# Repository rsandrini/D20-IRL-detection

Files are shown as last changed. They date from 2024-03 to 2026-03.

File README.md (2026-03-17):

# Real-time D20 Dice Detection with Raspberry Pi

Physical D20 dice roller with real-time face detection. A servo motor rolls the dice, a USB camera captures the result, and a YOLOv8n TFLite model running on a Raspberry Pi classifies which face is showing (1–20). Results are exposed via a Flask REST API and web UI.

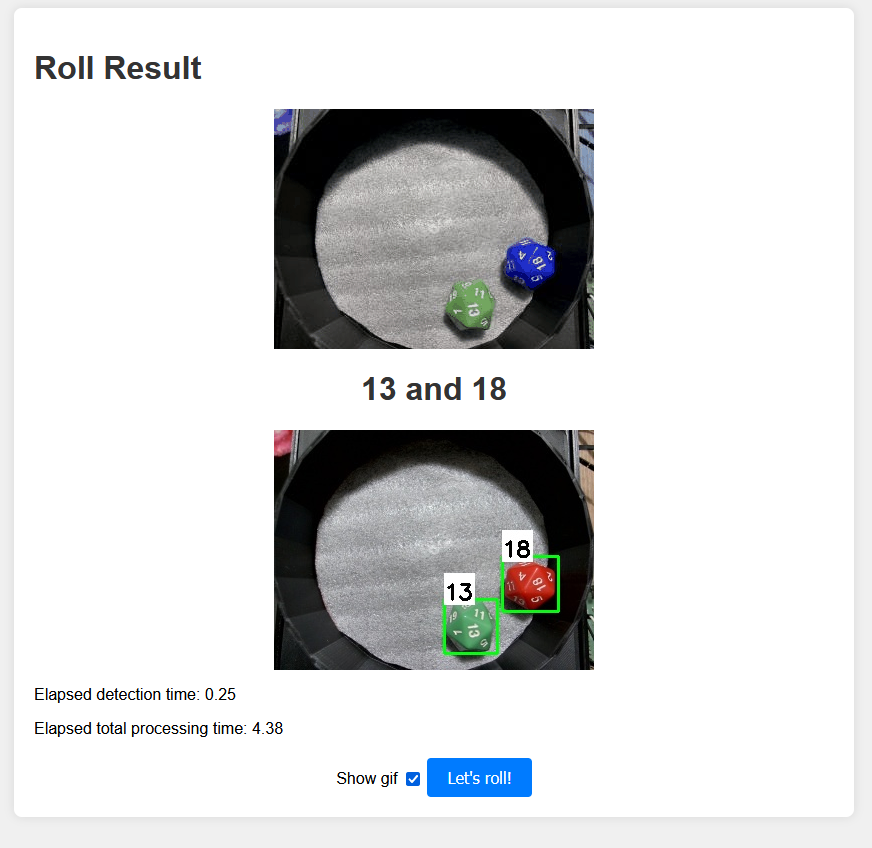
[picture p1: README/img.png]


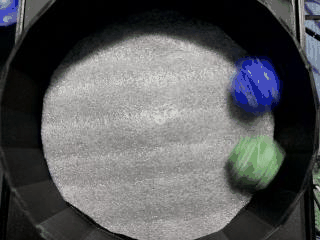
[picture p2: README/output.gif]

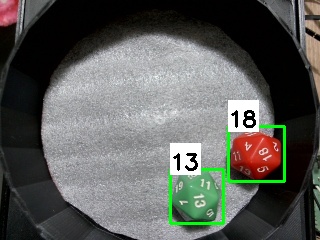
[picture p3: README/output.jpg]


## Hardware

- Raspberry Pi 3B+ or 4
- USB webcam (Logitech C920 or similar with manual focus support recommended)
- DC motor connected to GPIO pin 6 (via relay)
- 3D printed dice cup (STL files in `3d_model/stl/`)

## Setup

### Raspberry Pi (runtime)

```bash
python3 -m venv venv && source venv/bin/activate
pip install -r requirements-pi.txt
cp .env.example .env
```

Configure the camera crop region via the browser UI:
```bash
python3 main.py
# then open http://<pi-ip>:5000/calibrate
```

Or using the CLI script:
```bash
python3 scripts/select_roi.py
# paste the printed CAMERA_ROI value into .env
```

Optionally fix camera settings (exposure, white balance):
```bash
./fixcam.sh
```

### PC (training)

```bash
python3 -m venv venv && source venv/bin/activate
pip install -r requirements.txt
```

## Running

```bash
python3 main.py   # Flask app at http://<pi-ip>:5000
```

## Web UI Routes

| Route | Description |
|---|---|
| `GET /` | Roll page — trigger a roll and see the result |
| `GET /calibrate` | Live camera preview — set and save the ROI crop |
| `GET /label` | Label training images collected from the Pi |

## API

### POST /api/roll

Triggers the motor, captures a frame when motion stops, runs detection.

```json
{
  "detections": "7 and 14",
  "image": "static/results/<uuid>.jpg",
  "gif": "static/results/<uuid>.gif",
  "time_elapsed": 2.37,
  "time_elapsed_detection": 0.25
}
```

Add `debug=true` in the form body to generate a GIF of the roll.

## Environment Variables

See `.env.example`. Key variables:

| Variable | Default | Description |
|---|---|---|
| `RESULT_FOLDER` | `results` | Where output images/GIFs are saved (under `static/`) |
| `MODEL_FOLDER` | `tflite1/custom_model_lite` | Path to the TFLite model directory |
| `CAMERA_ROI` | _(empty)_ | Crop region `x,y,w,h` — set via `/calibrate` or `select_roi.py` |

## Model

**YOLOv8n** exported to INT8 TFLite for edge inference on Raspberry Pi.

- Model file: `tflite1/custom_model_lite/detect.tflite`
- Input: `640×640` RGB, float32 normalized (0–1)
- Output: `[1, 24, 8400]` — transposed to `[8400, 24]` (4 bbox coords + 20 class scores)
- Labels: hardcoded as `['1'..'20']` — no labelmap file needed
- ~3.2 MB, ~50ms inference on Pi 4

## Training Pipeline

The model must be trained on **your specific setup** (camera angle, dice type, lighting, bowl). The pipeline runs on a PC with a GPU.

### Step 1 — Collect training images (Pi)

Auto-rolls the dice N times and saves each captured frame to `to_label/`:

```bash
python3 scripts/collect_training_data.py --count 100
```

### Step 2 — Label images (browser)

Open `http://<pi-ip>:5000/label` while `main.py` is running.

For each image:
1. **Click and drag** to draw a bounding box around each die
2. **Click the face number** (1–20) for each box
3. **Save & Next** — saves image + Pascal VOC XML to `dice_training/`
4. **Skip** — discards bad images (blurry, dice on edge, etc.)

> Two dice per image is recommended — it matches the final usage and doubles labeling efficiency.

### Step 3 — Convert annotations (PC)

Converts Pascal VOC XML → YOLO format and splits into train/val sets:

```bash
python3 scripts/convert_voc_to_yolo.py
```

### Step 4 — Train (PC with GPU)

```bash
yolo train model=yolov8n.pt data=data/data.yaml epochs=150 imgsz=640 batch=16 patience=30
```

~5 minutes on an RTX 3080. Training results saved to `runs/detect/train/`.

### Step 5 — Export to TFLite INT8

```bash
yolo export model=runs/detect/train/weights/best.pt format=tflite imgsz=640 int8=True
```

### Step 6 — Deploy to Pi

```bash
cp runs/detect/train/weights/best_saved_model/best_int8.tflite tflite1/custom_model_lite/detect.tflite
git add tflite1/custom_model_lite/detect.tflite
git commit -m "Update model"
git push
```

On Pi:
```bash
git pull
```

### Retraining tips

- **Minimum ~100 labeled images** from your exact setup for reliable detection
- **Two dice per image** preferred — more annotations per roll
- After changing camera position or distance, collect new data and retrain from scratch
- Run `scripts/select_roi.py` or use `/calibrate` after any camera repositioning

## 3D Models

STL files for the dice cup and mechanical parts are in `3d_model/stl/`. A revised version with sloped inner walls (to guide dice toward center) is planned.

## TODO

- [ ] Revised 3D model with sloped bowl walls so dice settle in center
- [ ] Improve motion detection robustness (background subtraction)
- [ ] API authentication for external usage
- [ ] Queue system for concurrent requests

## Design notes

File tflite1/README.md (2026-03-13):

# TensorFlow Lite Object Detection on Android and Raspberry Pi
Train your own TensorFlow Lite object detection models and run them on the Raspberry Pi, Android phones, and other edge devices! 

<p align="center">
   
</p>

Get started with training on Google Colab by clicking the icon below, or [click here to go straight to the YouTube video that provides step-by-step instructions](https://youtu.be/XZ7FYAMCc4M).



## Introduction
TensorFlow Lite is an optimized framework for deploying lightweight deep learning models on resource-constrained edge devices. TensorFlow Lite models have faster inference time and require less processing power than regular TensorFlow models, so they can be used to obtain faster performance in realtime applications. 

This guide provides step-by-step instructions for how train a custom TensorFlow Object Detection model, convert it into an optimized format that can be used by TensorFlow Lite, and run it on edge devices like the Raspberry Pi. It also provides Python code for running TensorFlow Lite models to perform detection on images, videos, web streams, or webcam feeds.

## Step 1. Train TensorFlow Lite Models
### Using Google Colab (recommended)

The easiest way to train, convert, and export a TensorFlow Lite model is using Google Colab. Colab provides you with a free GPU-enabled virtual machine on Google's servers that comes pre-installed with the libraries and packages needed for training.

I wrote a [Google Colab notebook](./Train_TFLite2_Object_Detction_Model.ipynb) that can be used to train custom TensorFlow Lite models. It goes through the process of preparing data, configuring a model for training, training the model, running it on test images, and exporting it to a downloadable TFLite format so you can deploy it to your own device. It makes training a custom TFLite model as easy as uploading an image dataset and clicking Play on a few blocks of code!



Open the Colab notebook in your browser by clicking the icon above. Work through the instructions in the notebook to start training your own model. Once it's trained and exported, visit the [Setup TFLite Runtime Environment](#step-2-setup-tflite-runtime-environment-on-your-device) section to learn how to deploy it on your PC, Raspberry Pi, Android phone, or other edge devices.

### Using a Local PC
The old version of this guide shows how to set up a TensorFlow training environment locally on your PC. Be warned: it's a lot of work, and the guide is outdated. [Here's a link to the local training guide.](doc/local_training_guide.md)

## Step 2. Setup TFLite Runtime Environment on Your Device
Once you have a trained `.tflite` model, the next step is to deploy it on a device like a computer, Raspberry Pi, or Android phone.

> **Note:** This project uses `ai-edge-litert` (Google's successor to `tflite-runtime`) which supports Python 3.12+. Install it with:
> ```bash
> pip install ai-edge-litert opencv-python
> ```

To run the model, you'll need to set up the Python environment and directory structure. The [deploy_guides](deploy_guides) folder in this repository has step-by-step guides showing how to set up a TensorFlow environment on several different devices. Links to the guides are given below.

### Raspberry Pi
Follow the [Raspberry Pi setup guide](deploy_guides/Raspberry_Pi_Guide.md) to install TFLite Runtime on a Raspberry Pi 3 or 4 and run a TensorFlow Lite model. This guide also shows how to use the Google Coral USB Accelerator to greatly increase the speed of quantized models on the Raspberry Pi.

### Windows
Follow the instructions in the [Windows TFLite guide](deploy_guides/Windows_TFLite_Guide.md) to set up TFLite Runtime on your Windows PC using Anaconda!

### macOS
Still to come!

### Linux
Still to come!

### Android
Still to come!

### Embedded Devices
Still to come!

## Step 3. Run TensorFlow Lite Models!
There are four Python scripts to run the TensorFlow Lite object detection model on an image, video, web stream, or webcam feed. The scripts are based off the label_image.py example given in the [TensorFlow Lite examples GitHub repository](https://github.com/tensorflow/tensorflow/blob/master/tensorflow/lite/examples/python/label_image.py).

* [TFLite_detection_image.py](TFLite_detection_image.py)
* [TFLite_detection_video.py](TFLite_detection_video.py)
* [TFLite_detection_stream.py](TFLite_detection_stream.py)
* [TFLite_detection_webcam.py](TFLite_detection_webcam.py)

The following instructions show how to run the scripts. These instructions assume your .tflite model file and labelmap.txt file are in the `TFLite_model` folder in your `tflite1` directory as per the instructions given in the [Setup TFLite Runtime Environment](#step-2-setup-tflite-runtime-environment-on-your-device) guide.

<p align="center">
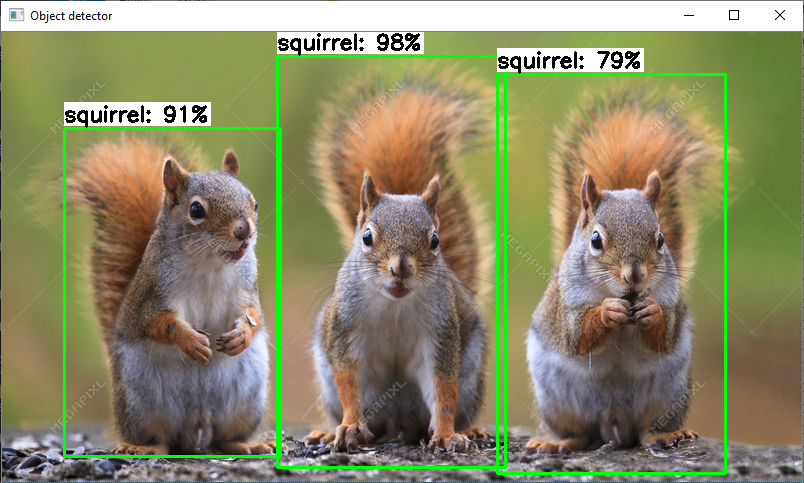
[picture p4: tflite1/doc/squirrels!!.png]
   
</p>

If you’d like try using the sample TFLite object detection model provided by Google, simply download it [here](https://storage.googleapis.com/download.tensorflow.org/models/tflite/coco_ssd_mobilenet_v1_1.0_quant_2018_06_29.zip), unzip it to the `tflite1` folder, and rename it to `TFLite_model`. Then, use `--modeldir=coco_ssd_mobilenet_v1_1.0_quant_2018_06_29` rather than `--modeldir=TFLite_model` when running the script. 

<details>
   <summary>Webcam</summary>
Make sure you have a USB webcam plugged into your computer.

From the project root, issue:

```
python3 tflite1/TFLite_detection_webcam.py --modeldir=tflite1/custom_model_lite
```

Optional arguments:
- `--threshold 0.5` — minimum confidence to display a detection (default: 0.5)
- `--nms_threshold 0.45` — NMS IoU threshold (default: 0.45)
- `--resolution 1280x720` — webcam resolution (default: 1280x720)

After a few moments of initializing, a window will appear showing the webcam feed. Detected D20 faces (1–20) will have bounding boxes and confidence labels drawn in real time. Press `q` to quit.

> **Note:** This script uses a YOLOv8n TFLite model with a single output tensor `[1, 24, 8400]`.
> Labels are hardcoded as 1–20 (no `labelmap.txt` needed). The `--labels` argument from the
> original SSD-MobileNet version has been removed.
</details>

<details>
   <summary>Video</summary>
To run the video detection script, issue:

```
python TFLite_detection_video.py --modeldir=TFLite_model
```

A window will appear showing consecutive frames from the video, with each object in the frame labeled. Press 'q' to close the window and end the script. By default, the video detection script will open a video named 'test.mp4'. To open a specific video file, use the `--video` option:

```
python TFLite_detection_video.py --modeldir=TFLite_model --video='birdy.mp4'
```

Note: Video detection will run at a slower FPS than realtime webcam detection. This is mainly because loading a frame from a video file requires more processor I/O than receiving a frame from a webcam.
</details>

<details>
   <summary>Web stream</summary>
To run the script to detect images in a video stream (e.g. a remote security camera), issue: 

```
python TFLite_detection_stream.py --modeldir=TFLite_model --streamurl="http://ipaddress:port/stream/video.mjpeg" 
```

After a few moments of initializing, a window will appear showing the video stream. Detected objects will have bounding boxes and labels displayed on them in real time.

Make sure to update the URL parameter to the one that is being used by your security camera. It has to include authentication information in case the stream is secured.

If the bounding boxes are not matching the detected objects, probably the stream resolution wasn't detected. In this case you can set it explicitly by using the `--resolution` parameter:

```
python TFLite_detection_stream.py --modeldir=TFLite_model --streamurl="http://ipaddress:port/stream/video.mjpeg" --resolution=1920x1080
```
</details>

<details>
   <summary>Image</summary>
To run the image detection script, issue:

```
python TFLite_detection_image.py --modeldir=TFLite_model
```

The image will appear with all objects labeled. Press 'q' to close the image and end the script. By default, the image detection script will open an image named 'test1.jpg'. To open a specific image file, use the `--image` option:

```
python TFLite_detection_image.py --modeldir=TFLite_model --image=squirrel.jpg
```

It can also open an entire folder full of images and perform detection on each image. There can only be images files in the folder, or errors will occur. To specify which folder has images to perform detection on, use the `--imagedir` option:

```
python TFLite_detection_image.py --modeldir=TFLite_model --imagedir=squirrels
```

Press any key (other than 'q') to advance to the next image. Do not use both the --image option and the --imagedir option when running the script, or it will throw an error.

To save labeled images and a text file with detection results for each image, use the `--save_results` option. The results will be saved to a folder named `<imagedir>_results`. This works well if you want to check your model's performance on a folder of images and use the results to calculate mAP with the [calculate_map_catchuro.py](./util_scripts) script. For example:

```
python TFLite_detection_image.py --modeldir=TFLite_model --imagedir=squirrels --save_results
```

The `--noshow_results` option will stop the program from displaying images.
</details>

**See all command options**

For more information on options that can be used while running the scripts, use the `-h` option when calling them. For example:

```
python TFLite_detection_image.py -h
```

If you encounter errors, please check the [FAQ section](https://github.com/EdjeElectronics/TensorFlow-Lite-Object-Detection-on-Android-and-Raspberry-Pi#FAQs) of this guide. It has a list of common errors and their solutions. If you can successfully run the script, but your object isn’t detected, it is most likely because your model isn’t accurate enough. The FAQ has further discussion on how to resolve this.

## Examples
(Still to come!) Please see the [examples](examples) folder for examples of how to use your TFLite model in basic vision applications.

## FAQs
<details>
<summary>What's the difference between the TensorFlow Object Detection API and TFLite Model Maker?</summary>
<br>
Google provides a set of Colab notebooks for training TFLite models called [TFLite Model Maker](https://www.tensorflow.org/lite/models/modify/model_maker). While their object detection notebook is straightfoward and easy to follow, using the [TensorFlow Object Detection API](https://github.com/tensorflow/models/tree/master/research/object_detection) for creating models provides several benefits:

* TFLite Model Maker only supports EfficientDet models, which aren't as fast as SSD-MobileNet models.
* Training models with the Object Detection API generally results in better model accuracy.
* The Object Detection API provides significantly more flexibility in model and training configuration (training steps, learning rate, model depth and resolution, etc).
* Google still [recommends using the Object Detection API](https://www.tensorflow.org/lite/examples/object_detection/overview#fine-tuning_models_on_custom_data) as the formal method for training models with large datasets.
</details>

<details>
<summary>What's the difference between training, transfer learning, and fine-tuning?</summary>
<br>
Using correct terminology is important in a complicated field like machine learning. In this notebook, I use the word "training" to describe the process of teaching a model to recognize custom objects, but what we're actually doing is "fine-tuning". The Keras documentation gives a [good example notebook](https://keras.io/guides/transfer_learning/) explaining the difference between each term.

Here's my attempt at defining the terms:

* **Training**: The process of taking a full neural network with randomly initialized weights, passing in image data, calculating the resulting loss from its predictions on those images, and using backpropagation to adjust the weights in every node of the network and reduce its loss. In this process, the network learns how to extract features of interest from images and correlate those features to classes. Training a model from scratch typically takes millions of training steps and a large dataset of 100,000+ images (such as ImageNet or COCO). Let's leave actual training to companies like Google and Microsoft!
* **Transfer learning**: Taking a model that has already been trained, unfreezing the last layer of the model (i.e. making it so only the last layer's weights can be modified), and retraining the last layer with a new dataset so it can learn to identify new classes. Transfer learning takes advantage of the feature extraction capabilities that have already been learned in the deep layers of the trained model. It takes the extracted features and recategorizes them to predict new classes.
* **Fine-tuning**: Fine-tuning is similar to transfer learning, except more layers are unfrozen and retrained. Instead of just unfreezing the last layer, a significant amount of layers (such as the last 20% to 50% of layers) are unfrozen. This allows the model to modify some of its feature extraction layers so it can extract features that are more relevant to the classes its trying to identify. This notebook (and the TensorFlow Object Detection API) uses fine-tuning.

In general, I like to use the word "training" instead of "fine-tuning", because it's more intuitive and understandable to new users.
</details>

<details>
<summary>Should I get a Google Colab Pro subscription?</summary>
<br>
If you plan to use Colab frequently for training models, I recommend getting a Colab Pro subscription. It provides several benefits:

* Idle Colab sessions remain connected for longer before timing out and disconnecting
* Allows for running multiple Colab sessions at once
* Priority access to TPU and GPU-enabled virtual machines
* Virtual machines have more RAM

Colab keeps track of how much GPU time you use, and cuts you off from using GPU-enabled instances once you reach a certain use time. If you get the message telling you you're cut off from GPU instances, then that's a good indicator that you use Colab enough to justify paying for a Pro subscription.
</details>

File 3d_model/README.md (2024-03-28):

## How to print and mount the hardware components

The hardware components for this project include the Raspberry Pi, servo motor, and camera module. To set up the hardware components, follow these steps:

### Raspberry Pi

1. Connect the Raspberry Pi to a specify GPIO port
2. Use a solenoid to activate the motor
3. If is a small motor with a reduction case, you can use the 5v output from the Raspberry Pi
4. if necessary configure the GPIO port to activate the motor in the dice.py file (TODO: Move the configuration to a configuration file)

In the dice file I defined the time for the motor to be activated, you can change this value to increase or decrease the time the motor is activated.

```python
# Part of dice.py code 

def hardware_activation():
    # Pin Definitions
    pin = 6  # GPIO 6
    roll_for = 0.3

    GPIO.setmode(GPIO.BCM)  # BCM is the Broadcom SOC channel designation for GPIO numbering
    GPIO.setup(pin, GPIO.OUT)  # Set pin as an output pin
    try:
        # Turn on the GPIO pin
        GPIO.output(pin, GPIO.HIGH)
        print(f"GPIO {pin} is ON")
        time.sleep(roll_for)  # Wait for 5 seconds

        # Turn off the GPIO pin
        GPIO.output(pin, GPIO.LOW)
        print(f"GPIO {pin} is OFF")
    finally:
        GPIO.cleanup()  # Clean up GPIO settings

```

I'm using a simple and default motor with a reduction case, like this one:

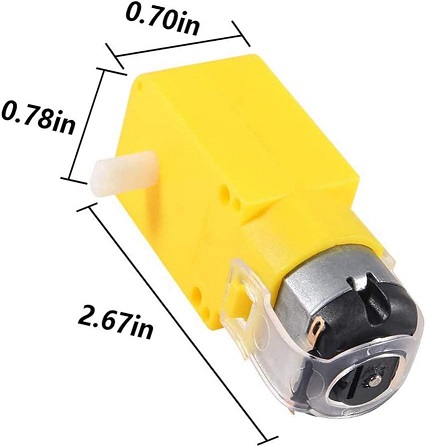
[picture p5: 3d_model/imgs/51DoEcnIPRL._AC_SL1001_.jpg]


DC Electric Motor 3V-6V Dual Shaft Geared TT Motor Magnetic Gearbox Engine, for Arduino Smart Car Robot

### Camera Module

I'm using an anker 2k camera with manual adjust for focus and zoom, you can use any camera usb module that you have.

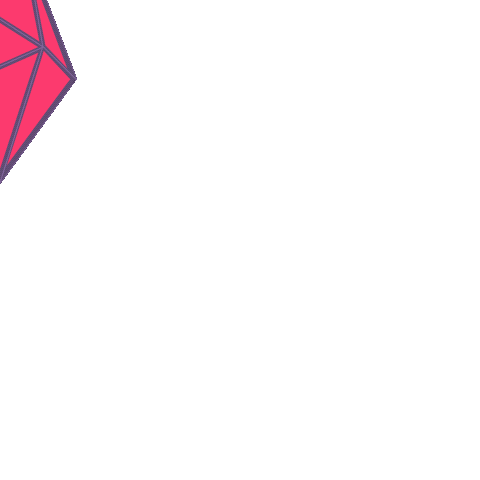
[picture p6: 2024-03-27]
static/gif/loading.gif

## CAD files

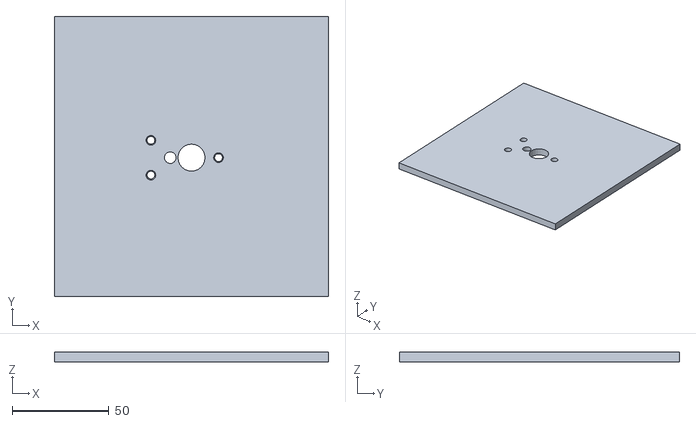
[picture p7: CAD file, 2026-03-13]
3d_model/stl/dice-irl-webcam-plate-v2.stl
142.0 x 145.0 x 5.00

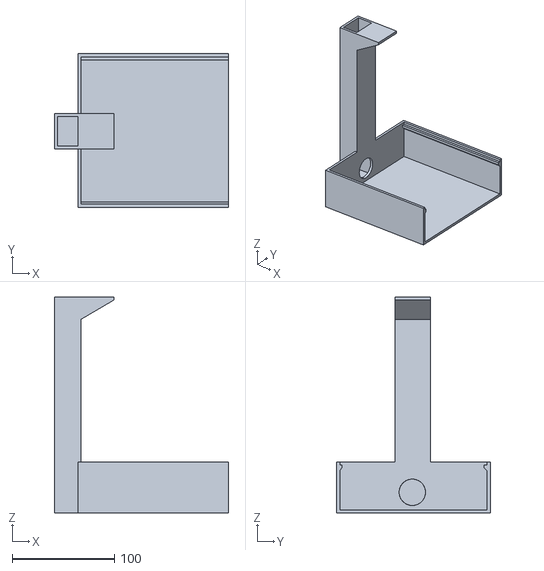
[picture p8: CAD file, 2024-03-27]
3d_model/stl/dice-IRL-webcam.stl
170.0 x 150.0 x 211.0

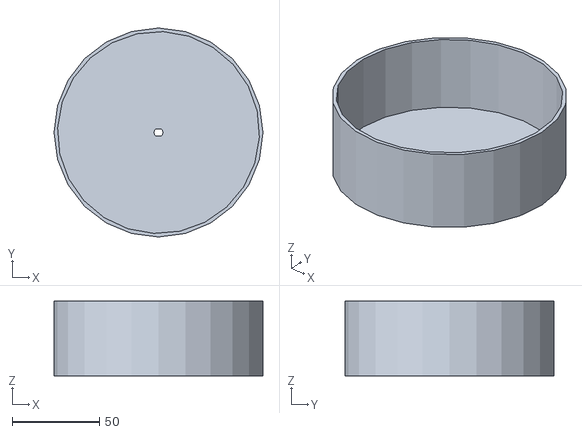
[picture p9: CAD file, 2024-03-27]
3d_model/stl/dice-IRL-webcam-cup.stl
120.0 x 120.0 x 43.0

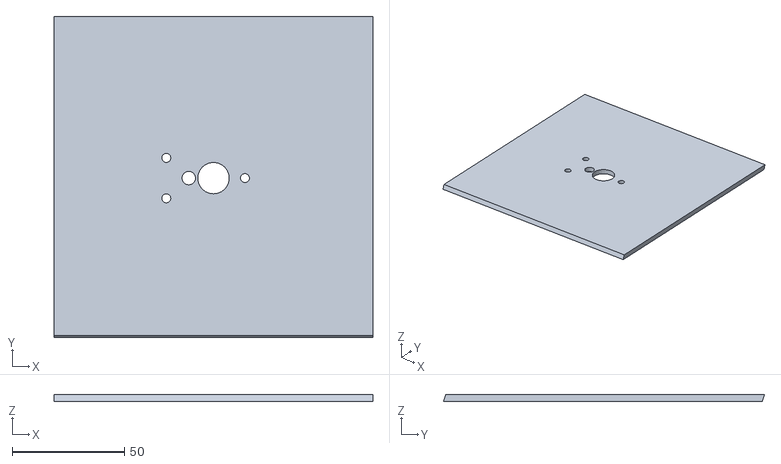
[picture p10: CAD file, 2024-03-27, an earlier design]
3d_model/stl/dice-IRL-webcam-plate.stl
142.0 x 143.0 x 3.00

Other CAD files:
3d_model/sketchup files/dice-IRL-webcam-cup.skp
3d_model/sketchup files/dice-IRL-webcam-plate.skp
3d_model/sketchup files/dice-IRL-webcam.skp

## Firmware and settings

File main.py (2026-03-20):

import base64
import json
import os
import uuid
import glob
import shutil
import threading
import time as _time
from functools import wraps
from xml.etree.ElementTree import Element, SubElement, tostring
from xml.dom import minidom
import cv2
import numpy as np
from flask import Flask, request, render_template, jsonify, redirect, url_for, send_from_directory, Response, session, stream_with_context, g
from object_detection import ObjectDetector
from dice import *
import db
import detectors as detector_registry

TO_LABEL_DIR = "to_label"
TRAINING_DIR = "dice_training"

from dotenv import load_dotenv
load_dotenv()

MODEL_FOLDER = os.getenv("MODEL_FOLDER")
RESULT_FOLDER = os.path.join("static", os.getenv("RESULT_FOLDER"))

app = Flask(__name__)
app.secret_key = os.getenv("SECRET_KEY", "dev-secret-change-me")
detector = ObjectDetector(MODEL_FOLDER)
db.init_db()

# Print local token to console for first-time setup
_local = db.get_user("local")
if _local and _local["token"]:
    print(f"\n  Local user token: {_local['token']}\n")



# ---------------------------------------------------------------------------
# RollQueue — single-threaded roll executor
# ---------------------------------------------------------------------------

class RollQueue:
    """Single-threaded roll executor. Each client_id gets one queue slot."""

    _MAX_RESULTS = 200

    def __init__(self):
        self._lock = threading.Lock()
        self._pending = []      # [{client_id, roll_id, params}]
        self._active  = None    # current item being executed
        self._results = {}      # roll_id -> {data, http_status}
        self._work    = threading.Event()

    def start(self):
        threading.Thread(target=self._loop, daemon=True).start()

    def submit(self, client_id, params):
        """Returns (roll_id, position). Position 0 = will roll next, 1+ = waiting."""
        with self._lock:
            if self._active and self._active["client_id"] == client_id:
                return self._active["roll_id"], 0
            for i, item in enumerate(self._pending):
                if item["client_id"] == client_id:
                    offset = 1 if self._active else 0
                    return item["roll_id"], i + offset
            roll_id = str(uuid.uuid4())
            offset  = 1 if self._active else 0
            pos     = len(self._pending) + offset
            self._pending.append({"client_id": client_id, "roll_id": roll_id, "params": params})
        self._work.set()
        return roll_id, pos

    def status(self, roll_id):
        with self._lock:
            if roll_id in self._results:
                r = self._results[roll_id]
                return {"status": "done", "result": r["data"], "http_status": r["http_status"]}
            if self._active and self._active["roll_id"] == roll_id:
                return {"status": "rolling", "position": 0, "queue_length": self._ql()}
            for i, item in enumerate(self._pending):
                if item["roll_id"] == roll_id:
                    offset = 1 if self._active else 0
                    return {"status": "queued", "position": i + offset, "queue_length": self._ql()}
        return {"status": "unknown"}

    def queue_length(self):
        with self._lock:
            return self._ql()

    def _ql(self):
        return len(self._pending) + (1 if self._active else 0)

    def _loop(self):
        while True:
            self._work.wait()
            self._work.clear()
            while True:
                with self._lock:
                    if not self._pending:
                        break
                    item = self._pending[0]
                    self._active = item
                try:
                    data, http_status = _do_roll(**item["params"])
                except Exception as e:
                    data, http_status = {"error": str(e)}, 500
                with self._lock:
                    self._pending.pop(0)
                    self._results[item["roll_id"]] = {"data": data, "http_status": http_status}
                    self._active = None
                    if len(self._results) > self._MAX_RESULTS:
                        oldest = next(iter(self._results))
                        del self._results[oldest]


roll_queue = RollQueue()

# Start queue worker (skip in werkzeug reloader child to avoid double-start)
if not app.debug or os.environ.get("WERKZEUG_RUN_MAIN") == "true":
    roll_queue.start()


# ---------------------------------------------------------------------------
# Helpers
# ---------------------------------------------------------------------------

def _get_param(key, default=None):
    """Read a param from JSON body, form data, or query string."""
    if request.is_json:
        return request.get_json(silent=True, force=True).get(key, default)
    val = request.form.get(key)
    if val is None:
        val = request.args.get(key)
    return val if val is not None else default


def _resolve_user():
    """Resolve caller to a user dict, or None if unauthenticated.
    Checks: Bearer token header → ?token query param → LOCAL_SUBNET IP bypass → admin session.
    """
    # 1. Bearer token in Authorization header
    auth = request.headers.get("Authorization", "")
    if auth.startswith("Bearer "):
        user = db.get_user_by_token(auth[7:].strip())
        if user and user["enabled"]:
            return dict(user)

    # 2. Token in query string (required for EventSource which cannot set headers)
    token = request.args.get("token", "").strip()
    if token:
        user = db.get_user_by_token(token)
        if user and user["enabled"]:
            return dict(user)

    # 3. IP subnet bypass — LOCAL_SUBNET env var (e.g. "192.168.1.0/24")
    subnet_str = os.getenv("LOCAL_SUBNET", "").strip()
    if subnet_str:
        try:
            from ipaddress import ip_network, ip_address
            if ip_address(request.remote_addr) in ip_network(subnet_str, strict=False):
                user = db.get_user("local")
                if user and user["enabled"]:
                    return dict(user)
        except ValueError:
            pass

    # 4. Admin session (browser login via /admin/login — only for admin UI pages)
    if session.get("is_admin") or not os.getenv("ADMIN_PASSWORD"):
        user = db.get_user("local")
        if user and user["enabled"]:
            return dict(user)

    return None


def require_auth(f):
    """Require any valid authenticated user. Sets g.current_user."""
    @wraps(f)
    def decorated(*args, **kwargs):
        user = _resolve_user()
        if not user:
            return jsonify({"error": "unauthorized"}), 403
        if not user.get("enabled"):
            return jsonify({"error": "user_disabled"}), 403
        g.current_user = user
        return f(*args, **kwargs)
    return decorated


def admin_required(f):
    """Require admin role. Sets g.current_user."""
    @wraps(f)
    def decorated(*args, **kwargs):
        user = _resolve_user()
        if not user:
            if request.is_json or request.accept_mimetypes.best == "application/json":
                return jsonify({"error": "unauthorized"}), 403
            return redirect(url_for("admin_login"))
        if user.get("role") != "admin":
            if request.is_json or request.accept_mimetypes.best == "application/json":
                return jsonify({"error": "admin_required"}), 403
            return redirect(url_for("admin_login"))
        g.current_user = user
        return f(*args, **kwargs)
    return decorated


def _blur_nonselected(frames, detections, selected, det_shape):
    """Blur non-selected dice regions in all GIF frames.
    Frames are 320x240 RGB; bboxes are in detection-frame pixel coords."""
    if not detections or not selected or not det_shape or len(detections) < 2:
        return frames
    H_det, W_det = det_shape[:2]
    if W_det == 0 or H_det == 0:
        return frames
    x_scale = 320 / W_det
    y_scale = 240 / H_det
    blur_bboxes = [
        [max(0, int(d["bbox"][0] * x_scale)), max(0, int(d["bbox"][1] * y_scale)),
         min(320, int(d["bbox"][2] * x_scale)), min(240, int(d["bbox"][3] * y_scale))]
        for d in detections if d is not selected and d.get("bbox")
    ]
    if not blur_bboxes:
        return frames
    result = []
    for frame in frames:
        f = frame.copy()
        for x1, y1, x2, y2 in blur_bboxes:
            if x2 > x1 and y2 > y1:
                f[y1:y2, x1:x2] = cv2.GaussianBlur(f[y1:y2, x1:x2], (51, 51), 0)
        result.append(f)
    return result


def _do_roll(user_id, mode, debug):
    """Core roll + detect logic. Returns (response_dict, http_status)."""
    max_retries = int(os.getenv("MAX_RETRIES", 3))
    start_time = _time.time()
    request_uuid = str(uuid.uuid4())
    time_elapsed_detection = 0
    detections = []
    frames, det_shape = [], None

    need = 2 if mode in ("advantage", "disadvantage") else 1
    got_enough = False

    for _ in range(max_retries):
        frames, det_shape = roll_dice(request_uuid, RESULT_FOLDER)
        if detector.interpreter is None:
            got_enough = True   # no model — don't retry, just proceed
            break
        det_start = _time.time()
        detections = detector.detect_objects(RESULT_FOLDER, f"{request_uuid}.jpg")
        time_elapsed_detection += round(_time.time() - det_start, 4)
        if len(detections) >= need:
            got_enough = True
            break

    if not got_enough and detector.interpreter is not None:
        if mode in ("advantage", "disadvantage"):
            time_elapsed = round(_time.time() - start_time, 2)
            return {"error": "could_not_detect_two_dice", "detections": detections,
                    "time_elapsed": time_elapsed}, 422
        # normal mode: no dice after all retries — return empty result, don't hard-fail

    # Select winner
    if mode == "advantage":
        selected = max(detections[:2], key=lambda d: d["face"]) if len(detections) >= 2 else None
    elif mode == "disadvantage":
        selected = min(detections[:2], key=lambda d: d["face"]) if len(detections) >= 2 else None
    else:
        selected = max(detections, key=lambda d: d["confidence"]) if detections else None

    image_path = f"{RESULT_FOLDER}/{request_uuid}.jpg"

    # Crop for normal mode
    if mode == "normal" and selected and selected.get("bbox"):
        crop_path = detector.crop_image(image_path, selected["bbox"], margin=20)
        if crop_path:
            image_path = crop_path

    gif_path = f"{RESULT_FOLDER}/{request_uuid}.gif"
    if debug and len(frames) > 1:
        t = _time.time()
        gif_frames = _blur_nonselected(frames, detections, selected, det_shape) if mode == "normal" else frames
        generate_gif_from_images(process_frames(gif_frames), gif_path)
        print(f"GIF generated in {_time.time() - t:.2f}s")

    time_elapsed = round(_time.time() - start_time, 2)
    time_elapsed_detection = round(time_elapsed_detection, 2)

    db.save_roll(
        request_uuid, user_id, mode, detections,
        selected["face"] if selected else None,
        image_path, gif_path, time_elapsed, time_elapsed_detection
    )

    return {
        "roll_id": request_uuid,
        "mode": mode,
        "detections": detections,
        "selected": selected,
        "image": image_path,
        "gif": gif_path,
        "time_elapsed": time_elapsed,
        "time_elapsed_detection": time_elapsed_detection,
    }, 200


# ---------------------------------------------------------------------------
# Local UI
# ---------------------------------------------------------------------------

@app.route('/', methods=['GET', 'POST'])
def page_roll_dice():
    if request.method == 'POST':
        return redirect(url_for('page_roll_dice'))
    return render_template('roll.html')


# ---------------------------------------------------------------------------
# /api/roll — async via queue
# ---------------------------------------------------------------------------

@app.route('/api/roll', methods=['POST'])
@require_auth
def api_roll_dice():
    client_id = _get_param("client_id") or request.headers.get("X-Client-Id") or g.current_user["id"]
    mode  = _get_param("mode", "normal")
    debug = bool(_get_param("debug", False))
    roll_id, position = roll_queue.submit(client_id, {
        "user_id": g.current_user["id"],
        "mode": mode,
        "debug": debug,
    })
    return jsonify({"roll_id": roll_id, "position": position, "queue_length": roll_queue.queue_length()})


@app.route('/api/roll/<roll_id>/stream')
@require_auth
def roll_stream(roll_id):
    def generate():
        while True:
            s = roll_queue.status(roll_id)
            yield f"data: {json.dumps(s)}\n\n"
            if s["status"] in ("done", "unknown"):
                return
            _time.sleep(0.5)
    return Response(
        stream_with_context(generate()),
        mimetype="text/event-stream",
        headers={"Cache-Control": "no-cache", "X-Accel-Buffering": "no"},
    )


@app.route('/api/roll/<roll_id>/status')
@require_auth
def roll_status(roll_id):
    return jsonify(roll_queue.status(roll_id))


# ---------------------------------------------------------------------------
# /api/roll/<roll_id>/report
# ---------------------------------------------------------------------------

@app.route('/api/roll/<roll_id>/report', methods=['POST'])
@require_auth
def report_roll(roll_id):
    data = request.get_json(silent=True) or {}
    raw = data.get("correct_faces")
    if raw is None:
        return jsonify({"error": "correct_faces required"}), 400
    if not isinstance(raw, list):
        raw = [raw]
    try:
        correct_faces = [int(v) for v in raw]
        if not all(1 <= v <= 20 for v in correct_faces):
            raise ValueError
    except (ValueError, TypeError):
        return jsonify({"error": "correct_faces must be list of ints 1–20"}), 400

    changed = db.report_roll(roll_id, correct_faces)
    if not changed:
        return jsonify({"error": "roll not found"}), 404
    return jsonify({"status": "ok"})


@app.route('/api/roll/<roll_id>/acknowledge', methods=['POST'])
@admin_required
def acknowledge_report(roll_id):
    db.acknowledge_report(roll_id)
    return jsonify({"status": "ok"})


@app.route('/api/auth/me')
@require_auth
def auth_me():
    u = g.current_user
    return jsonify({"id": u["id"], "role": u["role"], "enabled": u["enabled"]})


# ---------------------------------------------------------------------------
# /u/<username>/roll  and  /u/<username>/history
# ---------------------------------------------------------------------------

@app.route('/u/<username>/roll', methods=['POST'])
@require_auth
def user_roll(username):
    # Must be rolling as yourself or be an admin
    if g.current_user["id"] != username and g.current_user.get("role") != "admin":
        return jsonify({"error": "forbidden"}), 403

    user = db.get_user(username)
    if not user:
        return jsonify({"error": "user not found"}), 404
    if not user["enabled"]:
        return jsonify({"error": "user_disabled"}), 403

    daily_limit = user["daily_limit"]
    if daily_limit > 0 and db.get_user_roll_count_today(username) >= daily_limit:
        return jsonify({"error": "daily_limit_reached"}), 403

    client_id = _get_param("client_id") or f"user:{username}"
    mode  = _get_param("mode", "normal")
    debug = bool(_get_param("debug", False))
    roll_id, position = roll_queue.submit(client_id, {
        "user_id": username,
        "mode": mode,
        "debug": debug,
    })
    return jsonify({"roll_id": roll_id, "position": position, "queue_length": roll_queue.queue_length()})


@app.route('/u/<username>/history', methods=['GET'])
@require_auth
def user_history(username):
    if g.current_user["id"] != username and g.current_user.get("role") != "admin":
        return jsonify({"error": "forbidden"}), 403
    limit = int(request.args.get("limit", 20))
    rolls = db.get_rolls(user_id=username, limit=limit)
    return jsonify(rolls)


# ---------------------------------------------------------------------------
# /api/users  (user management)
# ---------------------------------------------------------------------------

@app.route('/api/users', methods=['GET'])
@admin_required
def list_users():
    return jsonify(db.list_users())


@app.route('/api/users', methods=['POST'])
@admin_required
def create_user():
    data = request.get_json(silent=True) or {}
    user_id = data.get("id", "").strip()
    if not user_id:
        return jsonify({"error": "id required"}), 400
    if db.get_user(user_id):
        return jsonify({"error": "user already exists"}), 409
    daily_limit = int(data.get("daily_limit", 0))
    role = data.get("role", "user")
    token = db.create_user(user_id, daily_limit, role)
    return jsonify({"id": user_id, "token": token, "daily_limit": daily_limit, "role": role}), 201


@app.route('/api/users/<username>', methods=['GET'])
@admin_required
def get_user(username):
    user = db.get_user(username)
    if not user:
        return jsonify({"error": "not found"}), 404
    today_count = db.get_user_roll_count_today(username)
    return jsonify({**dict(user), "rolls_today": today_count})


@app.route('/api/users/<username>', methods=['PUT'])
@admin_required
def update_user(username):
    if not db.get_user(username):
        return jsonify({"error": "not found"}), 404
    data = request.get_json(silent=True) or {}
    kwargs = {}
    if "enabled" in data:
        kwargs["enabled"] = int(bool(data["enabled"]))
    if "daily_limit" in data:
        kwargs["daily_limit"] = int(data["daily_limit"])
    if "role" in data and data["role"] in ("admin", "user"):
        kwargs["role"] = data["role"]
    db.update_user(username, **kwargs)
    return jsonify(dict(db.get_user(username)))


# ---------------------------------------------------------------------------
# /admin
# ---------------------------------------------------------------------------

@app.route('/routes')
def routes():
    return render_template('routes.html')


@app.route('/admin')
@admin_required
def admin():
    import json as _json
    users = db.list_users()
    rolls = db.get_rolls(limit=50)
    for r in rolls:
        try:
            r['detections_parsed'] = _json.loads(r['detections']) if r.get('detections') else []
        except Exception:
            r['detections_parsed'] = []
    reports = db.get_reports(only_unreviewed=False)
    for r in reports:
        try:
            r['detections_parsed'] = _json.loads(r['detections']) if r.get('detections') else []
            r['correct_faces_parsed'] = _json.loads(r['correct_faces']) if r.get('correct_faces') else []
        except Exception:
            r['detections_parsed'] = []
            r['correct_faces_parsed'] = []
    pending_reports = sum(1 for r in reports if not r.get('reviewed'))
    return render_template('admin.html', users=users, rolls=rolls, reports=reports, pending_reports=pending_reports)


@app.route('/admin/login', methods=['GET', 'POST'])
def admin_login():
    if request.method == 'POST':
        password = request.form.get('password', '')
        if password == os.getenv('ADMIN_PASSWORD', ''):
            session['is_admin'] = True
            return redirect(url_for('admin'))
        return render_template('admin_login.html', error='Wrong password')
    return render_template('admin_login.html')


@app.route('/admin/logout')
def admin_logout():
    session.pop('is_admin', None)
    return redirect(url_for('page_roll_dice'))


# ---------------------------------------------------------------------------
# Labeling routes (unchanged)
# ---------------------------------------------------------------------------

def _pending_images():
    os.makedirs(TO_LABEL_DIR, exist_ok=True)
    return sorted(glob.glob(os.path.join(TO_LABEL_DIR, "*.jpg")))


def _save_pascal_voc(filename, img_w, img_h, boxes):
    """Save Pascal VOC XML annotation matching existing training data format."""
    ann = Element("annotation")
    SubElement(ann, "folder").text = "dice_training"
    SubElement(ann, "filename").text = filename
    SubElement(ann, "path").text = os.path.join(TRAINING_DIR, filename)
    src = SubElement(ann, "source")
    SubElement(src, "database").text = "Unknown"
    size = SubElement(ann, "size")
    SubElement(size, "width").text = str(img_w)
    SubElement(size, "height").text = str(img_h)
    SubElement(size, "depth").text = "3"
    SubElement(ann, "segmented").text = "0"

    for box in boxes:
        obj = SubElement(ann, "object")
        SubElement(obj, "name").text = str(box["label"])
        SubElement(obj, "pose").text = "Unspecified"
        SubElement(obj, "truncated").text = "0"
        SubElement(obj, "difficult").text = "0"
        bnd = SubElement(obj, "bndbox")
        SubElement(bnd, "xmin").text = str(box["x1"])
        SubElement(bnd, "ymin").text = str(box["y1"])
        SubElement(bnd, "xmax").text = str(box["x2"])
        SubElement(bnd, "ymax").text = str(box["y2"])

    xml_str = minidom.parseString(tostring(ann)).toprettyxml(indent="\t")
    xml_filename = os.path.splitext(filename)[0] + ".xml"
    with open(os.path.join(TRAINING_DIR, xml_filename), "w") as f:
        f.write(xml_str)


@app.route('/to_label/<filename>')
def to_label_file(filename):
    return send_from_directory(TO_LABEL_DIR, filename)


@app.route('/label')
def label_index():
    pending = _pending_images()
    if not pending:
        return render_template('label.html', filename=None, total=0, remaining=0)
    return redirect(url_for('label_image', filename=os.path.basename(pending[0])))
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

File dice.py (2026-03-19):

import concurrent.futures
import random
from io import BytesIO
from PIL import Image
import cv2
import numpy as np
import os
import RPi.GPIO as GPIO
import time
from dotenv import load_dotenv

load_dotenv()


def _parse_roi():
    raw = os.getenv("CAMERA_ROI", "").strip()
    if not raw:
        return None
    try:
        x, y, w, h = [int(v) for v in raw.split(",")]
        return (x, y, w, h)
    except ValueError:
        print(f"WARNING: Invalid CAMERA_ROI value '{raw}', ignoring.")
        return None


CAMERA_ROI = _parse_roi()

# ---------------------------------------------------------------------------
# Persistent camera — opened once, reused across rolls to eliminate the
# ~500–1000ms VideoCapture(0) init cost that happened on every roll.
# ---------------------------------------------------------------------------
_cap = None


def _get_cap():
    """Return the shared camera, (re)initializing it if needed."""
    global _cap
    if _cap is not None and _cap.isOpened():
        return _cap
    # Release any stale handle before reinitializing
    if _cap is not None:
        _cap.release()
        _cap = None
    print("Initializing camera...")
    cap = cv2.VideoCapture(0)
    cap.set(cv2.CAP_PROP_FOURCC, cv2.VideoWriter_fourcc(*'MJPG'))
    cap.set(cv2.CAP_PROP_FRAME_WIDTH, 1920)
    cap.set(cv2.CAP_PROP_FRAME_HEIGHT, 1080)
    if not cap.isOpened():
        cap.release()
        raise RuntimeError("Camera failed to open at index 0")
    # Drain stale frames after a fresh open
    for _ in range(5):
        cap.read()
    _cap = cap
    return _cap


def release_camera():
    """Explicitly release the shared camera (e.g. to free it for calibration)."""
    global _cap
    if _cap is not None:
        _cap.release()
        _cap = None


def _apply_roi(frame):
    if CAMERA_ROI is None:
        return frame
    x, y, w, h = CAMERA_ROI
    return frame[y:y+h, x:x+w]


def hardware_activation():
    pin = 6  # GPIO 6

    GPIO.setmode(GPIO.BCM)
    GPIO.setup(pin, GPIO.OUT)
    try:
        # Shake pattern: rapid pulses to agitate the dice
        GPIO.output(pin, GPIO.HIGH)
        time.sleep(0.1)
        GPIO.output(pin, GPIO.LOW)
        time.sleep(0.3)

        # Final push: random duration so dice lands differently each roll
        roll_for = random.uniform(0.2, 0.4)
        GPIO.output(pin, GPIO.HIGH)
        print(f"GPIO {pin} rolling for {roll_for:.2f}s")
        time.sleep(roll_for)
        GPIO.output(pin, GPIO.LOW)
    finally:
        GPIO.cleanup()


def process_frames(frames):
    image_list = []
    for frame in frames[-25:]:
        frame_rgb = cv2.cvtColor(frame, cv2.COLOR_RGB2BGR)
        mem = BytesIO()
        Image.fromarray(frame_rgb).save(mem, format="JPEG")
        mem.seek(0)
        image_list.append(mem)
    return image_list


def generate_gif_from_images(image_list, gif_name):
    processed_images = [Image.open(mem) for mem in image_list]
    processed_images[0].save(
        gif_name,
        save_all=True,
        append_images=processed_images[1:],
        duration=10,
        loop=1
    )
    print(f"GIF saved at: {gif_name}")


def roll_dice(uuid, folder):
    cap = _get_cap()

    # Flush stale frames from the buffer (camera was idle between rolls).
    # 2 frames is enough — the buffer is small on MJPG cameras.
    for _ in range(2):
        cap.read()

    last_frame_gray = None
    frames_since_last_motion = 0
    frames = []             # GIF frames (small, RGB)
    detection_frame = None  # Full-res ROI frame for model inference

    # Auto-calibrate motion threshold from baseline noise before rolling.
    # 5 frames is enough for a stable noise-floor estimate.
    print("Calibrating motion baseline...")
    baseline_scores = []
    for _ in range(5):
        ret, frame = cap.read()
        if not ret:
            # Camera dropped — reinitialize and retry once
            release_camera()
            cap = _get_cap()
            ret, frame = cap.read()
            if not ret:
                continue
        small = cv2.resize(_apply_roi(frame), (480, 270), interpolation=cv2.INTER_AREA)
        gray = cv2.cvtColor(small, cv2.COLOR_BGR2GRAY)
        if last_frame_gray is not None:
            baseline_scores.append(np.mean(cv2.absdiff(gray, last_frame_gray)))
        last_frame_gray = gray

    noise_floor = np.mean(baseline_scores) if baseline_scores else 1.0
    motion_threshold = max(noise_floor * 3, noise_floor + 2.0)
    print(f"Noise floor: {noise_floor:.2f} → motion threshold: {motion_threshold:.2f}")
    last_frame_gray = None

    hardware_activation()

    # Minimum frames to capture before checking for stop.
    # At ~30fps: 30 frames ≈ 1s. Prevents exit before dice have started moving.
    MIN_ROLLING_FRAMES = 30
    # Consecutive still frames required to declare the dice settled.
    # At ~30fps: 20 frames ≈ 0.67s of stillness.
    STILL_FRAMES_REQUIRED = 20

    total_frames = 0

    while True:
        ret, frame = cap.read()
        if not ret:
            continue

        frame = _apply_roi(frame)
        # Downscale only for motion detection — keeps the loop fast on Pi
        small = cv2.resize(frame, (480, 270), interpolation=cv2.INTER_AREA)
        gray = cv2.cvtColor(small, cv2.COLOR_BGR2GRAY)

        if last_frame_gray is not None:
            diff = cv2.absdiff(gray, last_frame_gray)
            motion_score = np.mean(diff)

            if motion_score > motion_threshold:
                frames_since_last_motion = 0
            else:
                frames_since_last_motion += 1

            # Keep the most recent frame for detection (before resize)
            detection_frame = frame.copy()

            # Store GIF frame (small)
            gif_frame = cv2.resize(frame, (320, 240), interpolation=cv2.INTER_AREA)
            gif_frame = cv2.cvtColor(gif_frame, cv2.COLOR_BGR2RGB)
            frames.append(gif_frame)
            total_frames += 1

            if total_frames >= MIN_ROLLING_FRAMES and frames_since_last_motion >= STILL_FRAMES_REQUIRED:
                print(f"Motion stopped after {total_frames} frames ({frames_since_last_motion} still).")
                break

        last_frame_gray = gray  # small (480x270) for fast comparison

    # Save detection frame at full ROI resolution (not the tiny GIF size)
    cv2.imwrite(f'{folder}/{uuid}.jpg', detection_frame)

    print("Finishing...")
    # Camera stays open — no cap.release()
    return frames, detection_frame.shape  # (H, W, C) — used by caller for GIF generation


if __name__ == "__main__":
    RESULT_FOLDER = "results"
    uuid = "unique_id"
    roll_dice(uuid, RESULT_FOLDER)
    release_camera()

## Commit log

2024-03-27 Api2 (#1)
    API and initial page added
    [dice-IRL-webcam-cup.skp, dice-IRL-webcam-cup.stl, dice-IRL-webcam-plate.skp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]
2024-03-27 Fix README
    [dice-IRL-webcam-cup.skp, dice-IRL-webcam-cup.stl, dice-IRL-webcam-plate.skp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]
2024-03-28 Additional README for 3d models and hardware
    [dice-IRL-webcam-cup.skp, dice-IRL-webcam-cup.stl, dice-IRL-webcam-plate.skp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]
2026-03-13 New model training
    [dice-irl-webcam-plate-v2.stl, results.csv]
2026-03-13 New plate
    [dice-irl-webcam-plate-v2.stl]
2026-03-13 Fix requirements and TFLite imports
    [object_detection.py]
2026-03-17 add scripts to fix fov
    [dice.py]
2026-03-17 Fix ROI and dice processing core
    [dice.py]
2026-03-17 Update models
    [results.csv]
2026-03-17 Calibrate route
2026-03-17 Clean the shit data
    [results.csv]
2026-03-18 Check no models and do not fail
    [main.py, object_detection.py]
2026-03-18 Fix main label after detect one die
    [main.py]
2026-03-19 Fix camera conn issues
    [dice.py, main.py]
2026-03-19 Fix retry on API calls
    [main.py]
2026-03-19 Fix auth main error
    [main.py]
